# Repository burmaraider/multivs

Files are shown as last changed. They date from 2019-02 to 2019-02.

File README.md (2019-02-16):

# Multi VS. Game Boards

## Description

This board design will allow you to run up to 8 games per side on a Nintendo Vs. board. Larger games like wrecking crew will limit the amount of games you can have on this.

## Whats included

This repo includes the following:
- GERBER Files needed to send to a fab house
- Eagle CAD files so that you can modify this design further, and/or fix things. (both 7.x and 9.x files)
- Parts List (see bom.txt)
- **An application to package up ROM's so that you can burn to some flash memory** - coming soon

## Why do this?

Things should be free in this world. And if you don't agree, well, okay then.

## Final note

If you like this, please share and spread the love. If you have fixed anything, please share and upload back here.

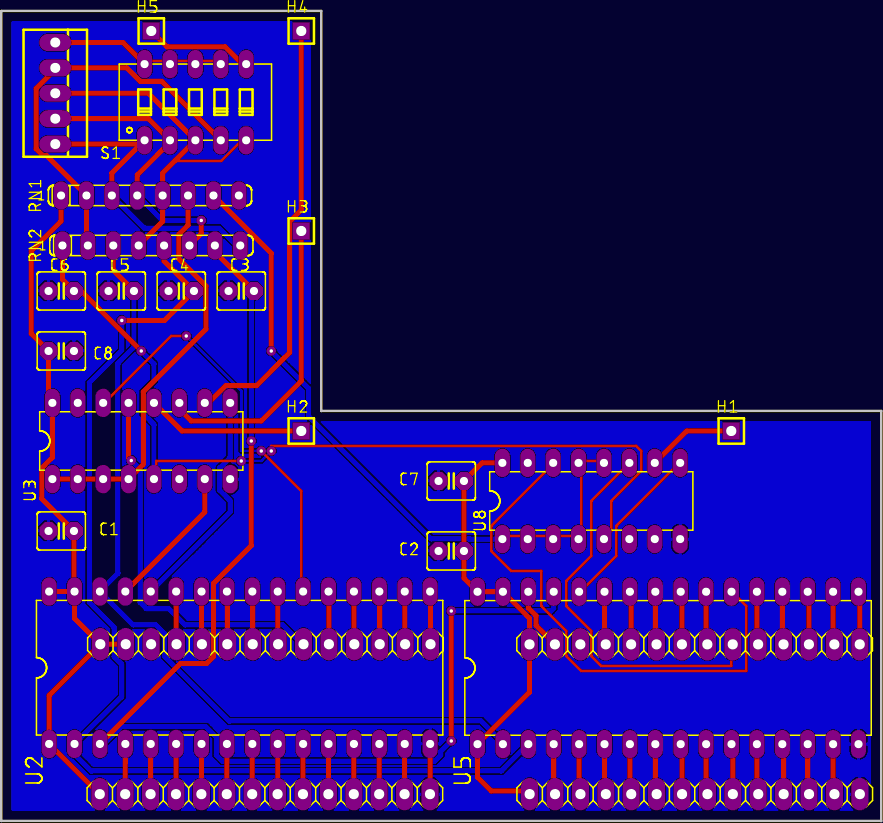
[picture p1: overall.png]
Multi Vs Board


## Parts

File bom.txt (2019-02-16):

QTY	  PART NUMBER		          DESCRIPTION			              LOCATION

2X	  DILB32P-223TLF		      32PIN DIP SOCKET		          U2, U5
2x	  SST39SF020A-70-4C-PHE	  32PIN FLASH MEMORY DIP		    U2,U5
2X	  SN74LS148N		          8-3 BINARY ENCODER		        U3, U8
1X	  4608X-102-102LF		      RESISTOR ARRAY 1KOHM 8 PIN	  RN1
1X	  4608X-102-680LF		      RESISTOR ARRAY 68OHM 8 PIN	  RN2
1X	  208-5			              DIP SWITCH 5 POS		          SW1
1x	  22-23-2051		          PIN HEADER 5 POS .100"		    J5
8X	  K104K15X7RF5TL2		      .1UF CERAMIC CAPACITORS		    C1-C8

The headers that poke into the Vs. board itself are standard .100" headers. Find them on Amazon or anywhere really.

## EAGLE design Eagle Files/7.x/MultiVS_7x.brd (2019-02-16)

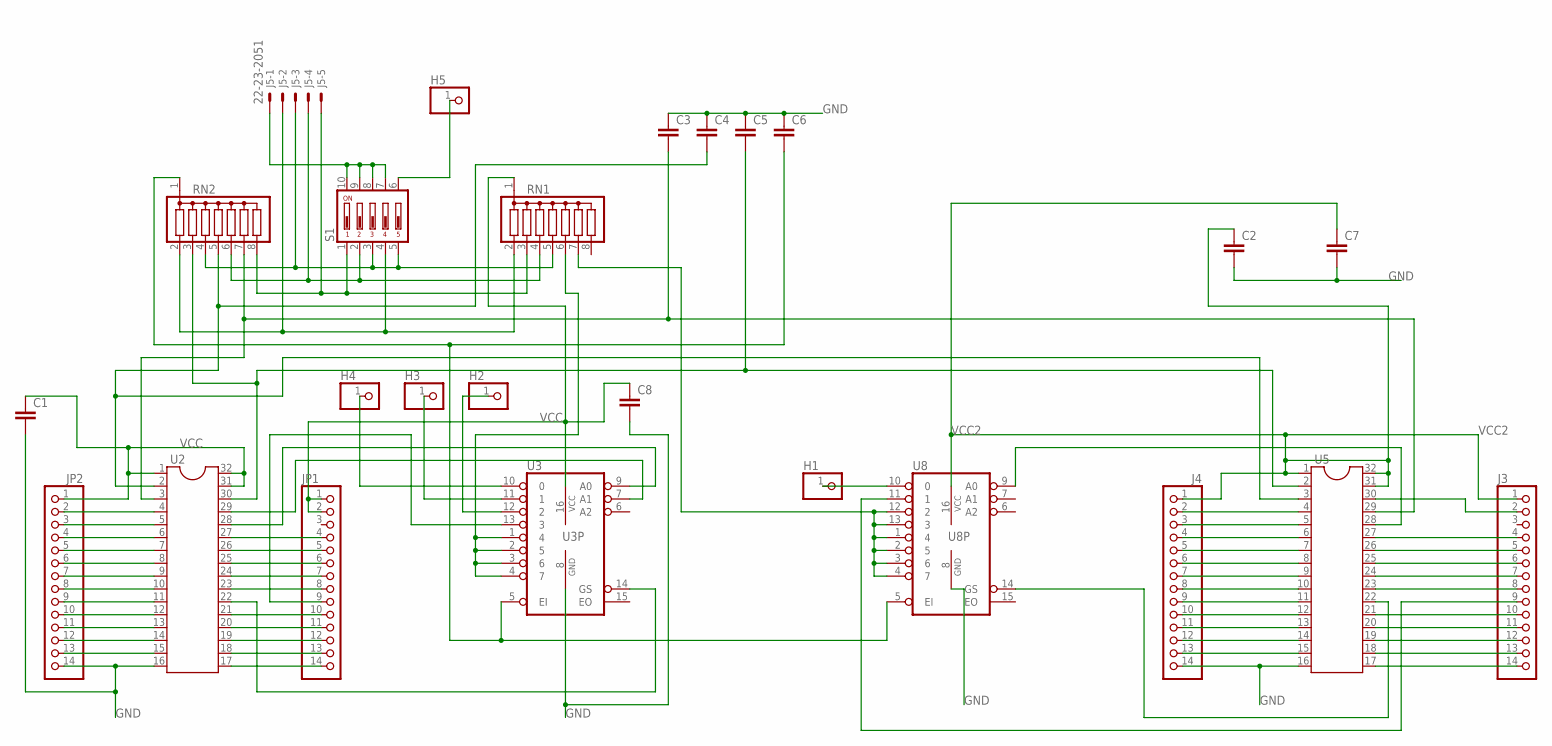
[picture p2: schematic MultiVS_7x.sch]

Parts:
C1, C2, C3, C4, C5, C6, C7, C8: C2.5/4; C2.5-4
H1, H2, H3, H4, H5: PINHD-1X1; 1X01
J3, J4: PINHD-1X14; 1X14
J5: 22-23-2051
JP1, JP2: PINHD-1X14; 1X14
RN1, RN2: G07R; SIL8
S1: DIP05YL
U2, U5: DIL32
U3, U8: 74LS148N; DIL16

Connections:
GND: C1.2, C2.2, C3.1, C4.1, C5.1, C6.1, C7.2, C8.2, J4.14, JP2.14, U2.16, U3.8 (GND), U5.16, U8.8 (GND)
unnamed: H1.1, U8.10 (0)
unnamed: H2.1, U3.12 (2)
unnamed: H3.1, U3.11 (1)
unnamed: H4.1, U3.10 (0)
unnamed: H5.1, S1.6
unnamed: JP2.13, U2.15
unnamed: JP2.12, U2.14
unnamed: JP2.11, U2.13
unnamed: JP2.10, U2.12
unnamed: JP2.9, U2.11
unnamed: JP2.8, U2.10
unnamed: JP2.7, U2.9
unnamed: JP2.6, U2.8
unnamed: JP2.5, U2.7
unnamed: JP2.4, U2.6
unnamed: JP2.3, U2.5
unnamed: J5.5, RN1.3, RN2.8, S1.1
unnamed: JP2.2, U2.4
unnamed: C3.2, RN2.7, U2.3, U5.29
unnamed: JP1.14, U2.17
unnamed: JP1.13, U2.18
unnamed: JP1.12, U2.19
unnamed: JP1.11, U2.20
unnamed: JP1.10, U2.21
unnamed: JP1.9, U3.13 (3)
unnamed: JP1.8, U2.23
unnamed: U2.22, U3.14 (GS)
unnamed: JP1.7, U2.24
unnamed: JP1.6, U2.25
unnamed: JP1.5, U2.26
unnamed: JP1.4, U2.27
unnamed: U2.28, U3.9 (A0)
unnamed: U2.29, U3.7 (A1)
unnamed: C4.2, RN2.5, U2.2, U5.3
unnamed: C5.2, RN2.3, U2.30, U5.2
unnamed: RN1.6, U3.1 (4), U3.2 (5), U3.3 (6), U3.4 (7)
unnamed: C6.2, RN2.1, U3.5 (EI), U8.5 (EI)
unnamed: U5.28, U8.9 (A0)
unnamed: J3.2, U5.30
unnamed: J5.1, S1.7, S1.8, S1.9, S1.10
unnamed: J5.4, RN1.4, RN2.6, S1.2
unnamed: J5.3, RN1.5, RN2.4, S1.3, S1.5
unnamed: RN1.7, U8.1 (4), U8.2 (5), U8.3 (6), U8.4 (7), U8.12 (2), U8.13 (3)
unnamed: J3.9, U8.11 (1)
unnamed: J4.13, U5.15
unnamed: J4.12, U5.14
unnamed: J5.2, RN1.2, RN2.2, S1.4
unnamed: J4.11, U5.13
unnamed: J4.10, U5.12
unnamed: J4.9, U5.11
unnamed: J4.8, U5.10
unnamed: J4.7, U5.9
unnamed: J4.6, U5.8
unnamed: J4.5, U5.7
unnamed: J4.4, U5.6
unnamed: J4.3, U5.5
unnamed: J4.2, U5.4
unnamed: J3.14, U5.17
unnamed: J3.13, U5.18
unnamed: J3.12, U5.19
unnamed: J3.11, U5.20
unnamed: J3.10, U5.21
unnamed: U5.22, U8.14 (GS)
unnamed: J3.8, U5.23
unnamed: J3.7, U5.24
unnamed: J3.6, U5.25
unnamed: J3.5, U5.26
unnamed: J3.4, U5.27
VCC: C1.1, C8.1, JP1.1, JP1.2, JP2.1, RN1.1, U2.1, U2.31, U2.32, U3.16 (VCC)
VCC2: C2.1, C7.1, J3.1, J4.1, U5.1, U5.31, U5.32, U8.16 (VCC)

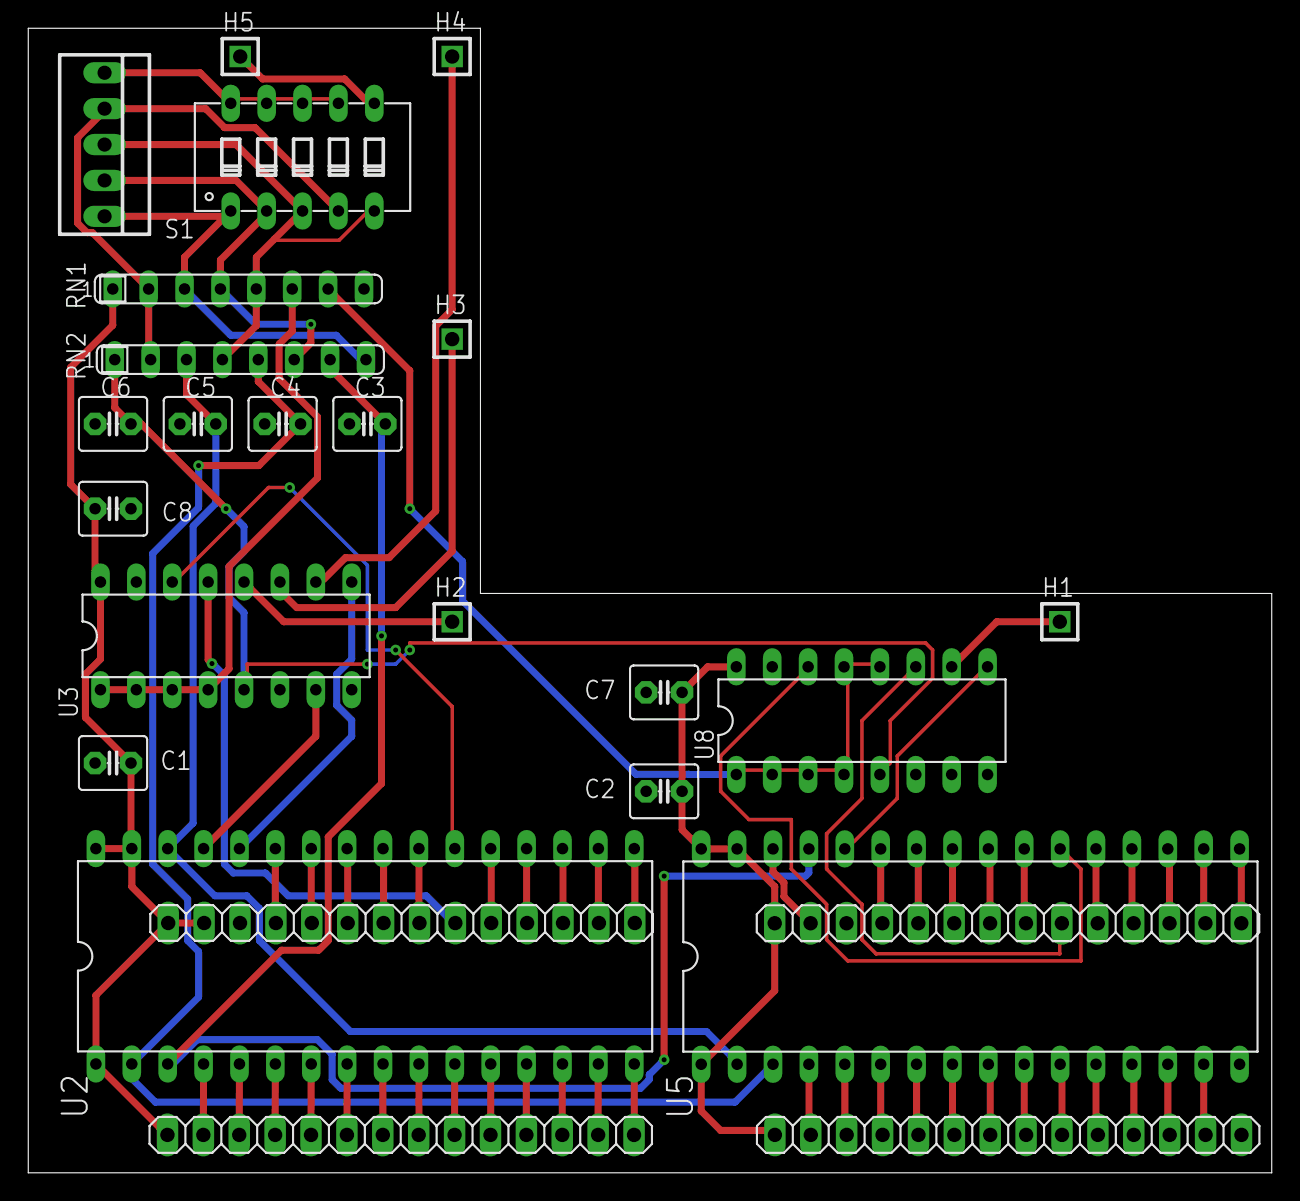
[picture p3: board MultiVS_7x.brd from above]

Board: 2 copper layers, 88.0 x 81.0 mm, 25 parts (0 on the bottom side), 71 nets.
